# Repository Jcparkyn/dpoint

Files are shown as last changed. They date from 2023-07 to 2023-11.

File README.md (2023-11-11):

# D-POINT: Digital Pen with Optical-Inertial Tracking

**D-POINT** is an open-source digital stylus that uses camera tracking and inertial measurements to achieve 6DoF (six degrees of freedom) inputs, with low latency, pressure sensitivity, and sub-millimetre accuracy.
The stylus can be used on any flat surface, and works with consumer-grade webcams.

<video src="https://github.com/Jcparkyn/dpoint/assets/51850908/21d00ce3-6456-4fba-8c24-4bc8e6642a0d" width="1920" height="1080" autoplay loop muted></video>

This project was part of my undergraduate thesis for electrical engineering. I've open-sourced the code and design files in the hopes that they might be useful to somebody, but it's not intended to be a "plug and play" DIY project. If you want to try building it anyway, follow the [setup guide](./setup-guide.md).

## Design

This is a very brief overview of how the system works. For all the details, plus literature review and lots of evaluation, read the full thesis (note: I haven't published this online yet).

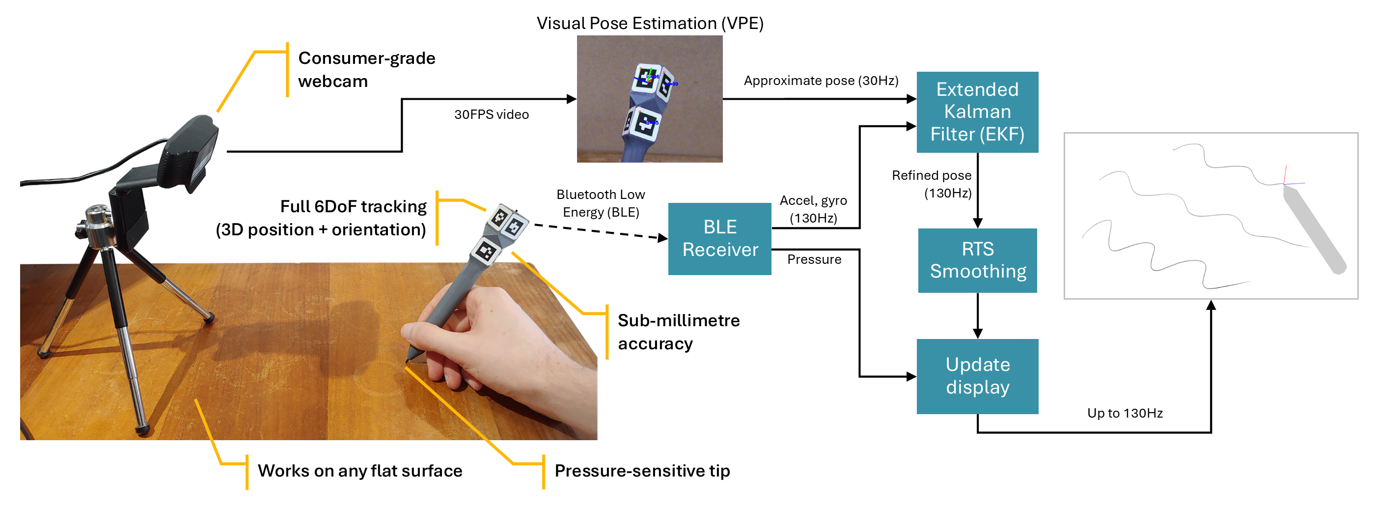
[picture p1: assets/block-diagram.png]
Block diagram showing how the system works


### Hardware

The main body of the stylus was 3D printed as two halves, shown below. The stylus contains a force sensor, a Li-ion battery which charges over USB-C, and an Arduino-based development board for logic and Bluetooth. Eight printed [ArUco](https://www.uco.es/investiga/grupos/ava/portfolio/aruco/) markers are glued to the back of the stylus, for visual pose estimation.

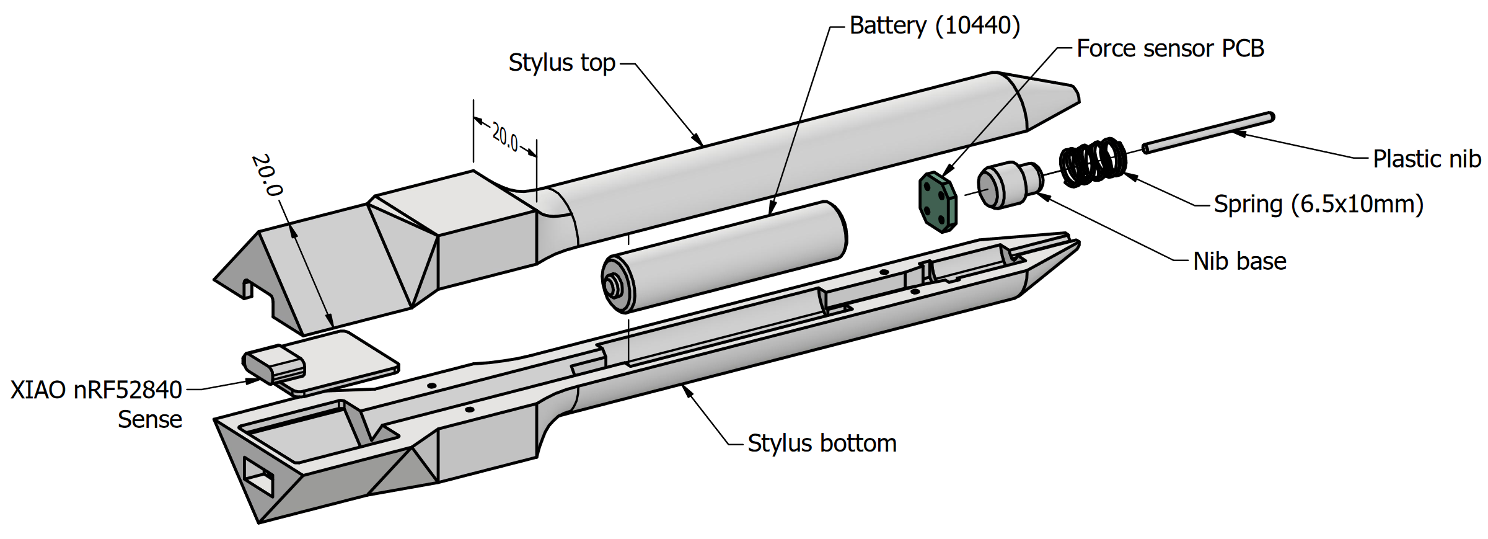
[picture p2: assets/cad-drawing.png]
CAD drawing showing the hardware design of the stylus


### Visual pose estimation (VPE)

The VPE process involves the four main steps:
1. **Marker detection:** First, we use OpenCV to detect the corners of each visible ArUco marker on the stylus.
1. **Rolling shutter correction:** We use a simple 2D motion model to estimate and correct for the effects of [rolling shutter](https://en.wikipedia.org/wiki/Rolling_shutter) on the observed corner locations.
1. **Perspective-n-Point (PnP):** From these corner positions, we use a [PnP](https://en.wikipedia.org/wiki/Perspective-n-Point) algorithm to estimate the pose of the stylus relative to the camera. When possible, we use the pose from the previous frame as a starting point to refine with virtual visual servoing (VVS), otherwise we fall back to SQPnP.
1. **Coordinate conversion:** Using the calibrated pose of the stylus and the drawing surface relative to the camera, we calculate the position and orientation of the stylus tip relative to the drawing surface.

### Inertial fusion

We use an Extended Kalman Filter (EKF) to fuse the VPE estimates with the inertial data from the accelerometer and gyroscope, and refine the estimates in real-time using the Rauch-Tung-Striebel (RTS) algorithm. To account for time delay from the camera frames, we use a negative-time measurement update algorithm. The EKF is implemented using NumPy and [Numba](https://numba.pydata.org/).

Using inertial measurements allows us to dramatically reduce latency compared to a camera-only implementation, while also improving accuracy and report rate for fast movements.

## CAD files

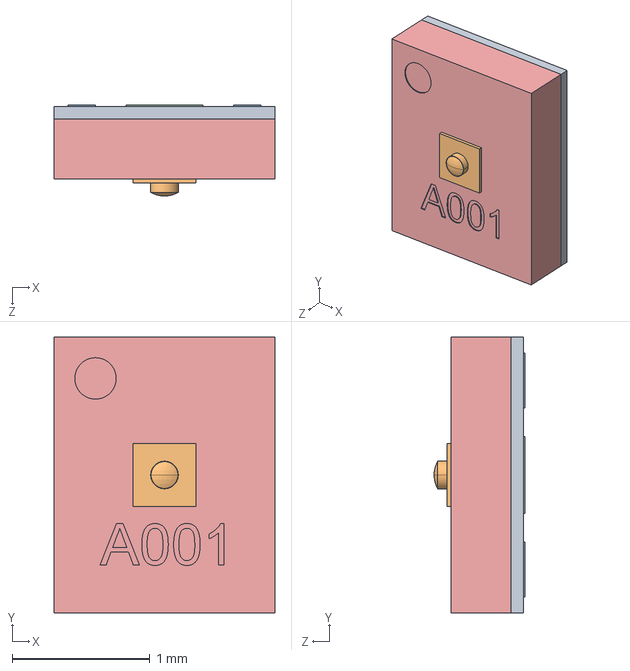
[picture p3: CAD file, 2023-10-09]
electronics/ForceSensor(HSFPAR003A).STEP
1.60 x 2.00 x 0.66 mm

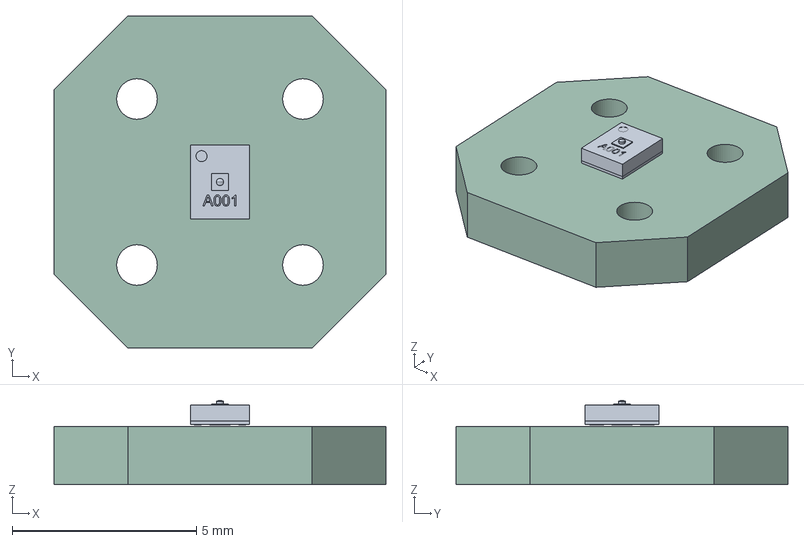
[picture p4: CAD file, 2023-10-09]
print/dpoint.step
9.00 x 9.00 x 2.28 mm
dpoint PCB

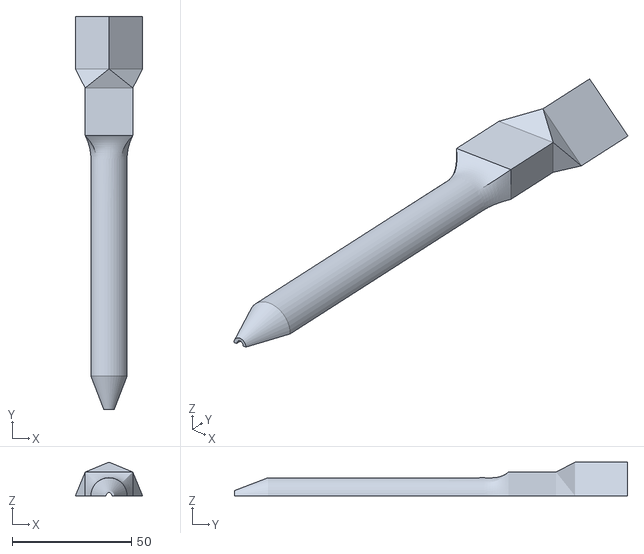
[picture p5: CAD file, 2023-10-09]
print/export/stylus_body_top.stl
28.3 x 165.0 x 14.1

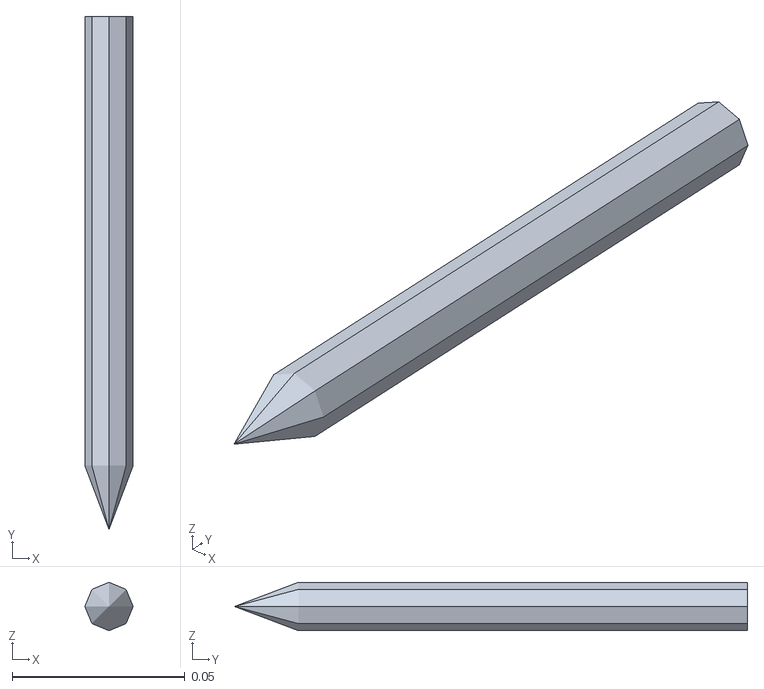
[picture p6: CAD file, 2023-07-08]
python/mesh/pen.obj
0.014 x 0.148 x 0.014

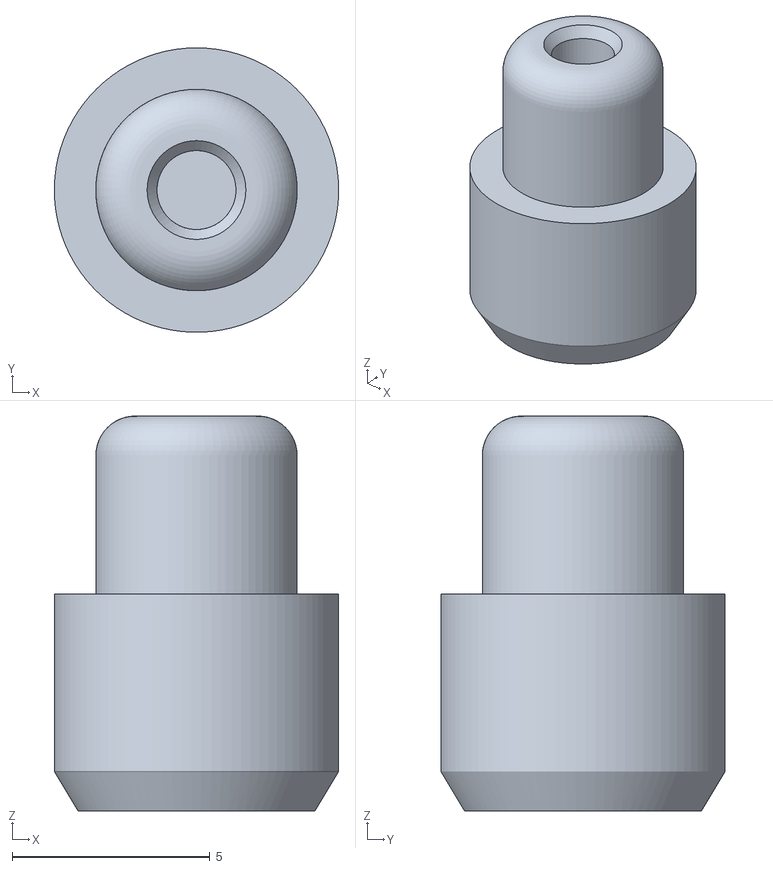
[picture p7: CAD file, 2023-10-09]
print/export/stylus_nib_base.stl
7.20 x 7.20 x 10.0

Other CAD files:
print/drawing.dwg
print/export/stylus_body_bottom.stl
print/Compress Spring11.ipt
print/assembly.iam
print/assembly.ipn
print/batt_10440.ipt
print/seed_arduino.ipt
print/stylus_body.ipt
print/stylus_nib.ipt
print/stylus_nib_base.ipt
python/mesh/pen.blend

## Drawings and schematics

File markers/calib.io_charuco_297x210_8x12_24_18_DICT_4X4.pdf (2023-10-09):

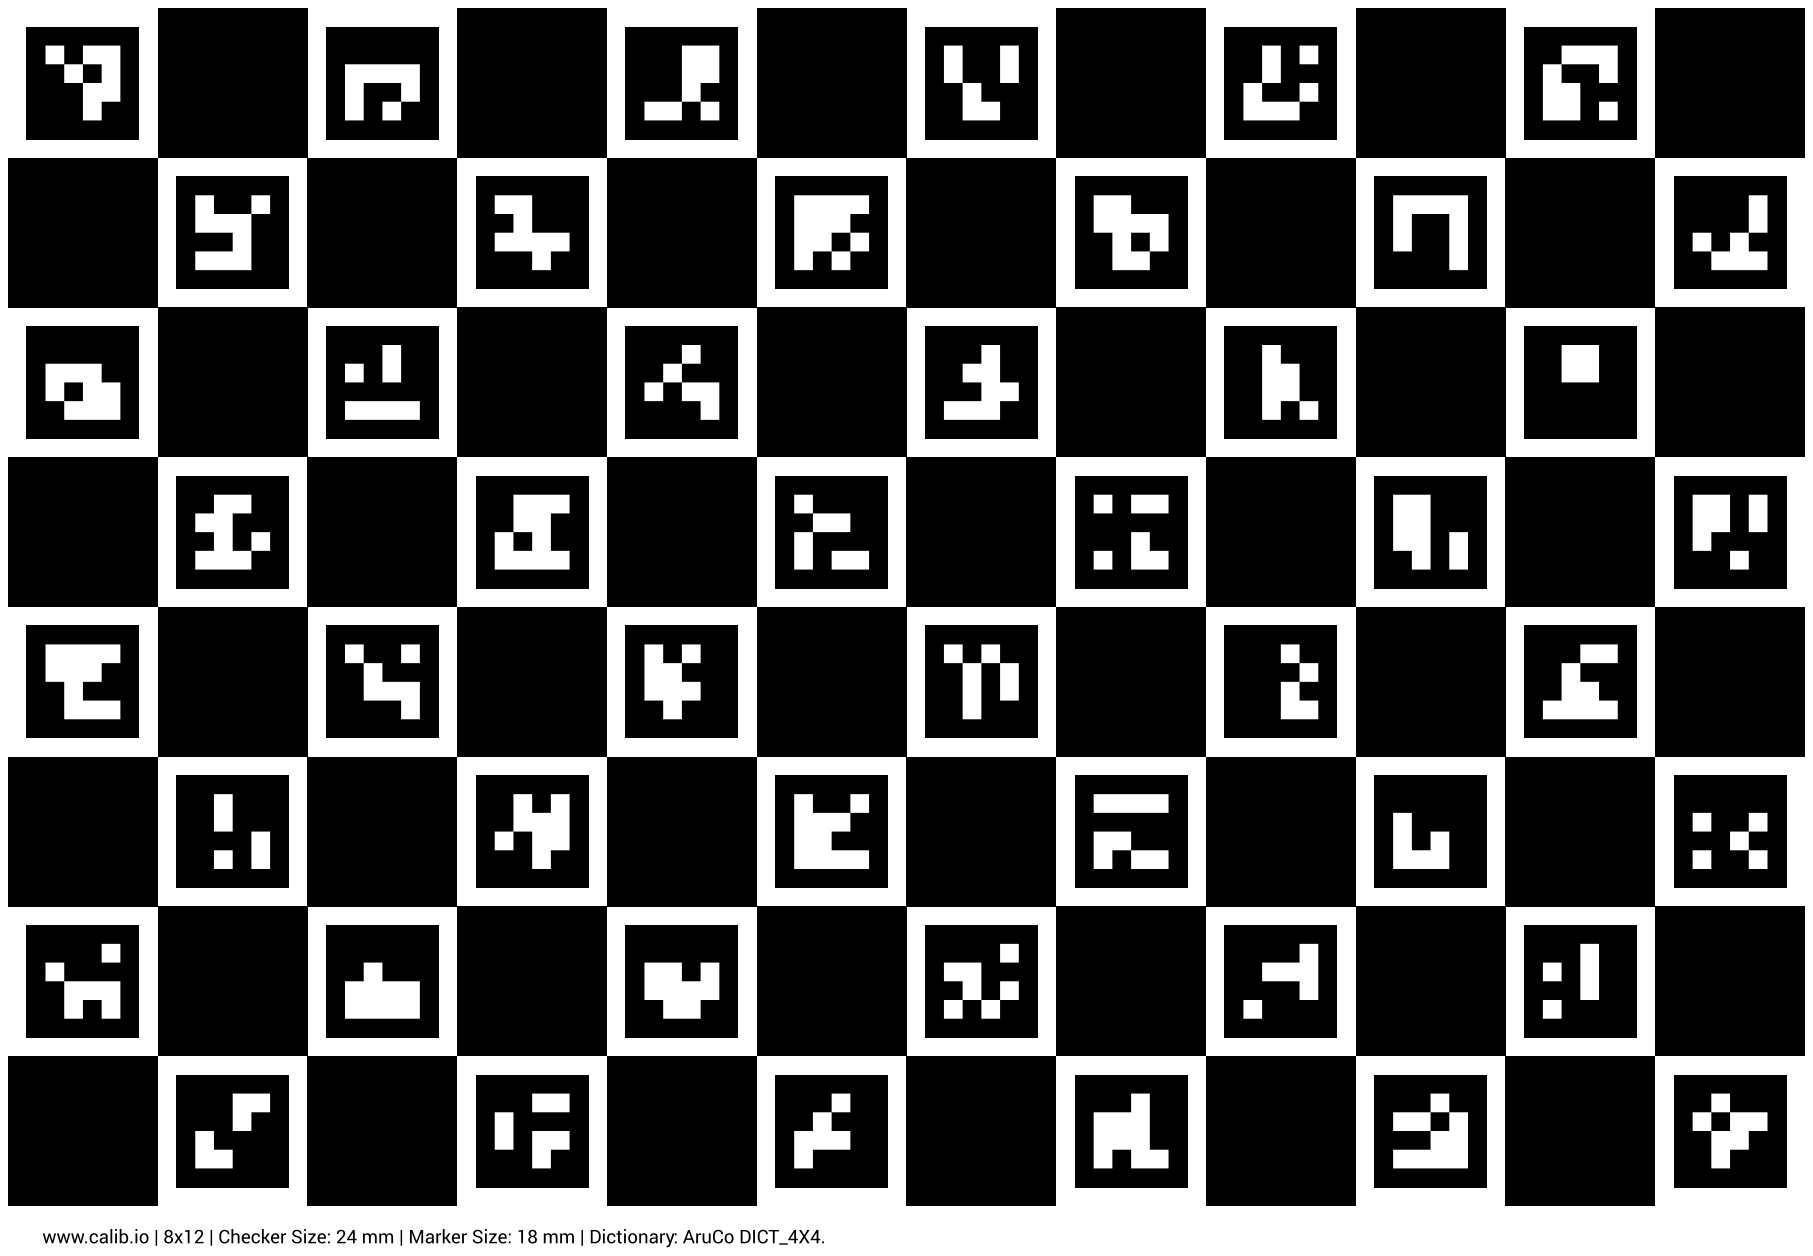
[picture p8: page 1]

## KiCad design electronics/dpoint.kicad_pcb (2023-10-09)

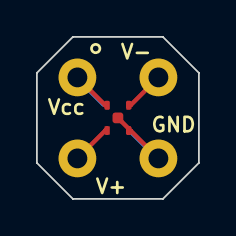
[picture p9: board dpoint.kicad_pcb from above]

Board: 2 copper layers, 9.0 x 9.0 mm, 6 parts (1 on the bottom side), 4 nets.

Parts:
C1: 0.1u; C_0805_2012Metric_Pad1.18x1.45mm_HandSolder
J1, J2, J3, J4: Conn_01x01_Socket; SolderWire-0.5sqmm_1x01_D0.9mm_OD2.1mm
U1: HSFPAR003A; Alps_HSFPAR003A

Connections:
unnamed: C1.1, J4.1, U1.1 (Vdd)
unnamed: J1.1, U1.4 (V1)
unnamed: J2.1, U1.2 (V2)
unnamed: C1.2, J3.1, U1.3 (GND)

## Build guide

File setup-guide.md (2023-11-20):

# Setup guide

As mentioned in the [readme](./README.md), the project is intended as a proof-of-concept (not a "plug-and-play" DIY project), so I can't guarantee that all steps will be easy or perfectly documented. If that's not enough to discourage you, follow the steps below to build and run D-POINT on your own hardware.

Before continuing, [clone](https://docs.github.com/en/repositories/creating-and-managing-repositories/cloning-a-repository) this repository using git:

```bash
git clone https://github.com/jcparkyn/dpoint.git
```

## Building the stylus

<details>
<summary><strong>Tools required</strong></summary>

- A 3D printer, for printing the stylus body. I used a Creality Ender 3, but most types of 3D printer should work.
- Hot air rework station, for soldering the force sensor. You might be able to make do with a soldering iron, but I wouldn't recommend it.
- A soldering iron, for soldering the other electronics.
- An inkjet or laser printer, for printing the ArUco markers.

</details>

<details>
<summary><strong>Parts required</strong></summary>

- Development board: [Seeed Studio XIAO nRF52840 Sense](https://www.seeedstudio.com/Seeed-XIAO-BLE-Sense-nRF52840-p-5253.html).
- Force sensor: Alps Alpine [HSFPAR003A](https://tech.alpsalpine.com/e/products/detail/HSFPAR003A/) or [HSFPAR004A](https://tech.alpsalpine.com/e/products/detail/HSFPAR004A/) (preferred). These can be a little hard to find, but unfortunately, there aren't many other off-the-shelf options aside from FSRs. The [HSFPAR007A](https://tech.alpsalpine.com/e/products/detail/HSFPAR007A/) will also work, but you'll have to modify the PCB footprint.
- Custom PCB: Order this from your PCB manufacturer of choice, using the provided [gerber files](./electronics/gerbers/). Use a PCB thickness of 1.6mm.
- Printer filament. I used PLA, but most hard plastics should work.
- A 6.5x10mm compression spring. I used one from a spring kit (like [this one](https://www.ebay.com.au/itm/175482659706)), but he spring tension does not need to match exactly.
- A 10440 lithium-ion battery (e.g., [this one](https://www.ebay.com/itm/194025159718)).
- Wire, 22-24 AWG for soldering.
- Something to use as a nib for the stylus. I used a [Wacom replacement nib](https://estore.wacom.com/en-au/wacom-standard-replacement-nibs-previous-gen.html), but you might be able to substitute this with something else (e.g., 3D printer filament). If you do, make sure to adjust the dimensions on the 3D model to match.

</details>

### Micro-controller code

To upload the code to the development board:
1. Follow [these instructions](https://wiki.seeedstudio.com/XIAO_BLE/#getting-started) to download the necessary software.
1. Open [microcontroller/dpoint-arduino](./microcontroller/dpoint-arduino/) in the Arduino IDE.
1. Connect the board to your computer using a USB-C cable.
1. Click **Tools > Board > Seeed nRF52 Boards > Seeed XIAO nRF52840 Sense**.
1. Upload the code.

### Build steps

1. Print all three STL files from [print/export/](./print/export/) on your 3D printer.
1. Solder the force sensor to the custom PCB. Make sure to align the top-left of the force sensor (marked with a very small circle) with the circle on the PCB.
1. Solder the force sensor PCB, battery, and development board together using wires, following the schematic below. Make sure to cut wires the right length to fit the stylus body.
1. Place the force sensor PCB, battery, and microcontroller into the bottom half of the 3D printed stylus. The stylus body also has a hole for a switch to disconnect the battery during development, but you can ignore this.
1. Find a small, flat piece of metal or hard plastic, and glue it to the back of the 3D printed nib base where it contacts the force sensor.
1. Insert the nib into the 3D printed nib base, then fit it into the front of the stylus using the spring. You may need to hold it in place until the stylus is fully assembled.
1. Add the top half of the stylus, and secure it in place using tape or glue.
1. Print out the ArUco markers from [markers/stylus-markers.pdf](./markers/stylus-markers.pdf) at 100% scale. This has two copies of each marker (and some spares), but you only need one.
1. Cut carefully along each of the lines around the markers. The white borders are important, so don't cut them off.
1. Glue the markers to the stylus using a glue stick (or your glue of choice). Place them according to the diagram below.
1. Finally, you'll also need a ChArUco board for camera calibration, which you can print using the pattern from [markers/](./markers/). You can either attach this to a flat board, or leave it on your desk.

Wiring diagram:



Marker placement:



## Software setup

The python code requires Python 3.11. I've tried to make sure the codebase works cross-platform, but it's currently only been tested on Windows 10.
You'll also need a relatively powerful CPU to run the application with its current settings. I used an i5-13600KF, but you should be able to get away with something a couple of generations older. If you have performance problems, try changing the settings in [configuration and tuning](#configuration-and-tuning).

1. Open the [python/](./python/) directory (`cd python`).
1. Create and activate a Python [virtual environment](https://docs.python.org/3/tutorial/venv.html#creating-virtual-environments) (optional, but recommended).
1. Install dependencies:
```bash
python -m pip install -r requirements.txt
```
1. Run the camera calibration script (see steps [below](#camera-calibration)). If you're using a Logitech C922 webcam like mine, you may be able to skip this step at the cost of some accuracy.
1. Optional, for better accuracy: Run the [marker calibration script](./python/calibrate_markers.py). Take at least 15 photos of the stylus from different angles (using your calibrated webcam), put them in the `IMAGE_PATH` directory for the script, then run the script.

## Running the application

Run [main.py](./python/main.py). If you have the `python` directory open in VSCode, you can do this by pressing <kbd>F5</kbd>, or running:
```bash
python -m main
```

Put the ChArUco board on your desk in view of the webcam, then press <kbd>C</kbd> (with the camera window focused) to calibrate the camera position.

Make sure the stylus is on - there should be a blue light (if not connected) or green light (if connected) near the USB port. If the stylus is asleep, shake it twice vertically to wake it up.

## Camera calibration
To calibrate your camera:
1. Take 5-10 photos of the ChArUco board from different angles using your webcam.
2. Put the images into `calibration_pics/f30/`.
3. Run `calibrate_camera.py`.

This calibrates the camera intrinsic parameters, but not the camera position or rotation. These are calibrated at run-time.

## Configuration and tuning
Most of the codebase is set up for my own hardware and requirements, so it might not work perfectly for other setups. Here are a list of things to check:

- **Camera exposure:** Auto-exposure is disabled, so you might need to adjust the exposure level in `marker_tracker.py`. Make it as low as you can without the markers failing to detect. Adding a light source will help.
- **Camera time delay:** The code tries to account for the time delay between the camera and IMU readings, which may be different on different systems. Adjust the value of `camera_delay` in `app.py` until you find the value that gives the best accuracy.
- **Camera focus:** The code tries to maintain focus on the stylus markers, but this relies on pre-measured focus values for my camera. If the focus looks wrong for your camera, try adjusting the values in `focus_targets` (`marker_tracker.py`).
- **RTS smoothing:** The filter uses RTS smoothing, which slightly improves accuracy but can be computationally intensive. If you have performance issues, set `smoothing_length` in `app.py` to a smaller value (or zero).
- **Marker search area:** The marker tracker tries to reduce the area of the frame where it looks for markers (this is the green box on the camera preview). If you have performance issues, adjust the value of `expand` in `marker_tracker.py` to reduce the search area for markers in each frame.
- **Camera frame rate:** This isn't directly exposed in the code, and depends on the camera you're using (OpenCV can't reliably set it), but you may want to try running your webcam at 15FPS (or another frame rate) instead of 30FPS. This should give relatively similar accuracy down to about 10-15FPS, and reduce computational requirements, but it might affect the `camera_delay`.
- **IMU update rate:** You can try adjusting the IMU update rate by changing `delayMs` in the [Arduino code](./microcontroller/dpoint-arduino/dpoint-arduino.ino). Make sure to update the corresponing `dt` in `app.py`, and test that the rate you chose is actually being achieved (this is limited by BLE settings and some other things). Ideally, `dt` should be computed automatically from timestamps in the BLE packets, but I removed this at one point and didn't get around to re-implementing it.
- **VSync:** For minimum latency, make sure to disable VSync in your graphics card settings.
- **Camera resolution:** If you try running this at a resolution other than 1920x1080, you'll probably have to tweak some other settings (and re-calibrate your camera).
- **Stylus length:** Depending on the nib you use, the length of your stylus might be slightly different than mine. Adjust `STYLUS_LENGTH` in `dimensions.py` to correct this.
- **Pressure sensor:** With the current wiring, the force sensor gets lots of interference when the USB cable is connected. Make sure to run it wirelessly for full accuracy. The code also tries to account for drift by re-calibrating the sensor whenever it's away from the page, but if you want to draw on 3D objects you'll need to disable this.

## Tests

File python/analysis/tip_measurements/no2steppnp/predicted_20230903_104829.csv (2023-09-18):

0.000988719 | 0.025962645 | 1.5081755e-05
0.0003994761 | 0.024874503 | -0.00031959818
-5.0939714e-05 | 0.02520879 | -0.00093396544
-0.00061105535 | 0.025585424 | -0.0004126248
0.0006081067 | 0.025196314 | -0.0011514479
-5.0023114e-05 | 0.026214939 | -0.000998219
-0.0011631214 | 0.025433293 | -0.0007946275
-0.0015963342 | 0.024322614 | 0.0003280963
-0.0009729329 | 0.024746282 | -0.0004860177
8.127195e-05 | 0.024458982 | -0.0009467948
-2.3815928e-05 | 0.14483851 | -0.00057031884
0.00033275783 | 0.14404711 | -0.00069739425
0.00021030256 | 0.14434724 | -0.0005502042
-0.00033741855 | 0.14444739 | -0.00045044706
-0.00017841718 | 0.14336857 | -0.0003970959
-0.00019879515 | 0.1433702 | -0.00028272715
-7.8505254e-05 | 0.14329271 | -0.00032725665
0.0009281744 | 0.1466855 | -0.0006902015
0.00079110765 | 0.14337167 | -0.00027919322
-0.00011933327 | 0.14356677 | -0.00014511406
0.0003138622 | 0.26272592 | -0.0006527511
0.0008508221 | 0.26250455 | -0.0011773211
-0.00033299095 | 0.26208067 | -0.000637439
0.001032939 | 0.26248762 | -0.00091222115
0.0006040647 | 0.26181027 | -0.0008861628
-0.00066502753 | 0.2594022 | -0.0012327172
0.0010597635 | 0.26068798 | -0.0006799782
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

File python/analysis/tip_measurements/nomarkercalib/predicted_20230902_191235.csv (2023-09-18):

0.0014141263 | 0.024553621 | 5.8834168e-05
0.0023236386 | 0.02523166 | -8.966219e-05
0.0015790227 | 0.026338127 | -0.0005602371
0.00024782165 | 0.025628017 | -0.00014026067
0.00094174786 | 0.025512496 | 6.263566e-05
0.0004122328 | 0.14360198 | 6.1106846e-05
0.00093417586 | 0.14414872 | -0.0002516737
0.0010865261 | 0.14363435 | -0.00031100702
0.0006521406 | 0.14537634 | -2.2045893e-05
0.0015282324 | 0.14462824 | -0.0006252238
-0.00018699863 | 0.1444019 | 0.00024900382
-0.0006599318 | 0.14404143 | 0.0004414377
0.0007905522 | 0.14370933 | -0.00021530614
0.0014647718 | 0.14423636 | -0.00011577799
0.0014899628 | 0.14449194 | -7.174196e-05
0.0009383219 | 0.024725506 | 0.00010030966
0.0013567837 | 0.02567877 | 0.00013983343
-6.125108e-06 | 0.024196347 | -0.00048550405
0.0016938101 | 0.025339687 | -6.674391e-05
-0.0007620022 | 0.026337849 | 0.0004691193
0.00052437466 | 0.2635748 | 2.0806963e-05
0.00069621496 | 0.2642158 | 0.0001255706
0.0007566231 | 0.26430744 | -0.00048155617
0.00046326534 | 0.26376262 | -0.00016481453
-0.00022522412 | 0.26451325 | 0.00019521681
-0.001210059 | 0.26380408 | 0.00024083661
-0.00036001968 | 0.2630329 | -5.96105e-06
0.0010297245 | 0.2633452 | -0.00033040126
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

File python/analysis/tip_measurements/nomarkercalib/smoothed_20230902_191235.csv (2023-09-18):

0.0016742414 | 0.024450984 | 5.7748148e-05
0.0018236212 | 0.02506619 | -2.1763663e-05
0.0013008809 | 0.025562134 | -0.0003653401
0.00043026748 | 0.025447594 | -0.00015804893
0.0011996034 | 0.024831023 | -0.00016407818
0.00019753393 | 0.14342597 | -0.00015245653
0.0010958357 | 0.14434528 | -0.00013294857
0.0015905233 | 0.14361745 | -0.00016152325
0.0010257148 | 0.14490484 | -9.178967e-05
0.0014786121 | 0.14416517 | -0.0003871435
-2.3638711e-05 | 0.14406408 | 0.00023682184
-0.00079716014 | 0.14315985 | 0.00028282715
0.0006409988 | 0.14352158 | -0.0002710929
0.0014790358 | 0.14449689 | -0.00020674539
0.0020802314 | 0.14439535 | -3.66339e-05
0.00094449334 | 0.024958648 | -6.465695e-05
0.0018162183 | 0.02506369 | -4.1450796e-05
0.00023790926 | 0.025245018 | -0.0002989177
0.001561813 | 0.024836395 | -0.00011486184
-0.0005173678 | 0.025556246 | 0.0002932321
0.0009506509 | 0.26418257 | -0.000264499
0.00097116426 | 0.26452184 | 3.196023e-05
0.00017269785 | 0.26383412 | -0.0005285385
0.00014483406 | 0.2641118 | -0.00022902
0.0005305559 | 0.26477817 | 0.00014491081
-0.00069827586 | 0.262862 | 0.00018413611
-0.00038334014 | 0.2625968 | -6.1392406e-05
0.00055882183 | 0.2635401 | -0.00037180036
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

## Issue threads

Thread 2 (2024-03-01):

UKF Implementation

TsingLoo, 2024-03-01:
I want to propose the consideration of implementing the Unscented Kalman Filter (UKF) instead of the current Extended Kalman Filter (EKF) for sensor fusion in the project.

I wonder, if it's possible to encapsulate the actual filter implementation by using abstract or interface-like calls in the update_imu and update_camera functions.

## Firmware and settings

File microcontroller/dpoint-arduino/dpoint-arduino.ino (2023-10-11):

#include <Adafruit_SPIFlash.h>
#include <LSM6DS3.h>
#include <Wire.h>
#include <bluefruit.h>
#include <nrf52840.h>
#include <nrf_saadc.h>
#include <nrf_power.h>

#define LEDR LED_RED
#define LEDG LED_GREEN
#define LEDB LED_BLUE

#define PRESSURE_SENSOR_VCC_PIN D1
#define PRESSURE_SENSOR_SAADC_CHANNEL 0

const unsigned long delayMs = 7;
const unsigned long rate = 1000/delayMs;
const unsigned long stayAwakeTimeMs = 1000*60;

struct IMUDataPacket {
  int16_t accel[3];
  int16_t gyro[3];
  uint16_t pressure;
};

const uint8_t LBS_UUID_SERVICE[] =
{
  0x19, 0xB1, 0x00, 0x10, 0xE8, 0xF2, 0x53, 0x7E, 0x4F, 0x6C, 0xD1, 0x04, 0x76, 0x8A, 0x12, 0x14
};

// 19B10013-E8F2-537E-4F6C-D104768A1214
const uint8_t LBS_UUID_CHR_IMU[] =
{
  0x14, 0x12, 0x8A, 0x76, 0x04, 0xD1, 0x6C, 0x4F, 0x7E, 0x53, 0xF2, 0xE8, 0x13, 0x00, 0xB1, 0x19
};

BLEService bleService(LBS_UUID_SERVICE);
BLECharacteristic imuCharacteristic(LBS_UUID_CHR_IMU);

Adafruit_FlashTransport_QSPI flashTransport;
LSM6DS3 imu(I2C_MODE, 0x6A); //I2C device address 0x6A

const nrf_saadc_channel_config_t adcConfig = {
  .resistor_p = NRF_SAADC_RESISTOR_DISABLED,
  .resistor_n = NRF_SAADC_RESISTOR_DISABLED,
  .gain       = NRF_SAADC_GAIN4,
  .reference  = NRF_SAADC_REFERENCE_VDD4,
  .acq_time   = NRF_SAADC_ACQTIME_20US,
  .mode       = NRF_SAADC_MODE_DIFFERENTIAL,
  .burst      = NRF_SAADC_BURST_ENABLED,
};

// Disable QSPI flash to save power
void QSPIF_sleep(void)
{
  flashTransport.begin();
  flashTransport.runCommand(0xB9);
  flashTransport.end();
}

void imuISR() {
  // Interrupt triggers for both single and double taps, so we need to check which one it was.
  uint8_t tapSrc;
  status_t status = imu.readRegister(&tapSrc, LSM6DS3_ACC_GYRO_TAP_SRC);
  bool wasDoubleTap = (tapSrc & LSM6DS3_ACC_GYRO_DOUBLE_TAP_EV_STATUS_DETECTED) > 0;
  if (!wasDoubleTap) {
    nrf_power_system_off(NRF_POWER);
  }
}

void setupWakeUpInterrupt()
{
  // Tap interrupt code is based on code by daCoder
  // https://forum.seeedstudio.com/t/xiao-sense-accelerometer-examples-and-low-power/270801
  imu.settings.gyroEnabled = 0;
  imu.settings.accelEnabled = 1;
  imu.settings.accelSampleRate = 104;
  imu.settings.accelRange = 2;
  imu.begin();

  //https://www.st.com/resource/en/datasheet/lsm6ds3tr-c.pdf
  imu.writeRegister(LSM6DS3_ACC_GYRO_TAP_CFG1, 0b10001000); // Enable interrupts and tap detection on X-axis
  imu.writeRegister(LSM6DS3_ACC_GYRO_TAP_THS_6D, 0b10001000); // Set tap threshold
  const int duration = 0b0010 << 4; // 1LSB corresponds to 32*ODR_XL time
  const int quietTime = 0b10 << 2; // 1LSB corresponds to 4*ODR_XL time
  const int shockTime = 0b01 << 0; // 1LSB corresponds to 8*ODR_XL time
  imu.writeRegister(LSM6DS3_ACC_GYRO_INT_DUR2, duration | quietTime | shockTime); // Set Duration, Quiet and Shock time windows
  imu.writeRegister(LSM6DS3_ACC_GYRO_WAKE_UP_THS, 0x80); // Single & double-tap enabled (SINGLE_DOUBLE_TAP = 1)
  imu.writeRegister(LSM6DS3_ACC_GYRO_MD1_CFG, 0x08); // Double-tap interrupt driven to INT1 pin
  imu.writeRegister(LSM6DS3_ACC_GYRO_CTRL6_G, 0x10); // High-performance operating mode disabled for accelerometer

  // Set up the sense mechanism to generate the DETECT signal to wake from system_off
  pinMode(PIN_LSM6DS3TR_C_INT1, INPUT_PULLDOWN_SENSE);
  attachInterrupt(digitalPinToInterrupt(PIN_LSM6DS3TR_C_INT1), imuISR, CHANGE);

  return;
}

void setupPressureSensor() {
  pinMode(PRESSURE_SENSOR_VCC_PIN, OUTPUT);
  digitalWrite(PRESSURE_SENSOR_VCC_PIN, HIGH);

  nrf_saadc_enable(NRF_SAADC);

  nrf_saadc_oversample_set(NRF_SAADC, NRF_SAADC_OVERSAMPLE_32X);
  nrf_saadc_resolution_set(NRF_SAADC, NRF_SAADC_RESOLUTION_12BIT);
  nrf_saadc_channel_input_set(NRF_SAADC, PRESSURE_SENSOR_SAADC_CHANNEL, NRF_SAADC_INPUT_AIN2, NRF_SAADC_INPUT_AIN4);
  nrf_saadc_channel_init(NRF_SAADC, PRESSURE_SENSOR_SAADC_CHANNEL, &adcConfig);

  NRF_SAADC->TASKS_CALIBRATEOFFSET = 1;
  while (NRF_SAADC->EVENTS_CALIBRATEDONE == 0);
  NRF_SAADC->EVENTS_CALIBRATEDONE = 0;
  while (NRF_SAADC->STATUS == (SAADC_STATUS_STATUS_Busy << SAADC_STATUS_STATUS_Pos));

  nrf_saadc_disable(NRF_SAADC);
}

int16_t readPressure() {
  volatile nrf_saadc_value_t result = -1;

  nrf_saadc_enable(NRF_SAADC);
  nrf_saadc_continuous_mode_disable(NRF_SAADC);

  NRF_SAADC->RESULT.MAXCNT = 1;
  NRF_SAADC->RESULT.PTR = (uint32_t)&result;

  // Start the SAADC and wait for the started event.
  NRF_SAADC->TASKS_START = 1;
  while (NRF_SAADC->EVENTS_STARTED == 0);
  NRF_SAADC->EVENTS_STARTED = 0;

  // Do a SAADC sample, will put the result in the configured RAM buffer.
  NRF_SAADC->TASKS_SAMPLE = 1;
  while (NRF_SAADC->EVENTS_END == 0);
  NRF_SAADC->EVENTS_END = 0;

  NRF_SAADC->TASKS_STOP = 1;
  while (NRF_SAADC->EVENTS_STOPPED == 0);
  NRF_SAADC->EVENTS_STOPPED = 0;

  nrf_saadc_disable(NRF_SAADC);

  // Scaling to match previous mbed implementation
  return int16_t((uint32_t(result) * 0xFFFF) / 0x0FFF);
}

void setupImu() {
  imu.settings.accelRange = 4; // Can be: 2, 4, 8, 16
  imu.settings.gyroRange = 500; // Can be: 125, 245, 500, 1000, 2000
  imu.settings.accelSampleRate = 416; //Hz.  Can be: 13, 26, 52, 104, 208, 416, 833, 1666, 3332, 6664, 13330
  imu.settings.gyroSampleRate = 416; //Hz.  Can be: 13, 26, 52, 104, 208, 416, 833, 1666
  imu.settings.accelBandWidth = 200;
  imu.settings.gyroBandWidth = 200;
  imu.begin();
}

void runBle() {
  while (Bluefruit.connected(0)) {
    unsigned long startTime = millis();

    IMUDataPacket packet;
    // This could be optimised by reading all values as a block.
    packet.accel[0] = imu.readRawAccelX();
    packet.accel[1] = imu.readRawAccelY();
    packet.accel[2] = imu.readRawAccelZ();
    packet.gyro[0] = imu.readRawGyroX();
    packet.gyro[1] = imu.readRawGyroY();
    packet.gyro[2] = imu.readRawGyroZ();

    packet.pressure = readPressure();
    
    imuCharacteristic.notify(&packet, sizeof(packet));

    // Inaccurate but usable way to throttle the rate of measurements.
    unsigned long time = millis() - startTime;
    unsigned long waitPeriod = delayMs - time;
    if (waitPeriod > 0 && waitPeriod < 500) { // protection against overflow issues
      delay(waitPeriod);
    }
  }
}

void startAdvertising()
{
  Bluefruit.Advertising.addFlags(BLE_GAP_ADV_FLAGS_LE_ONLY_GENERAL_DISC_MODE);
  Bluefruit.Advertising.addTxPower();
  Bluefruit.Advertising.addService(bleService);

  Bluefruit.ScanResponse.addName();
  
  Bluefruit.Advertising.restartOnDisconnect(true);
  Bluefruit.Advertising.setInterval(128, 488);    // in unit of 0.625 ms
  Bluefruit.Advertising.setFastTimeout(30);      // number of seconds in fast mode
  Bluefruit.Advertising.start(0);                // 0 = Don't stop advertising after n seconds
}

void sleepUntilDoubleTap() {
  digitalWrite(LEDR, HIGH);
  digitalWrite(LEDG, HIGH);
  digitalWrite(LEDB, HIGH);

  Serial.println("Setting up interrupt");
  // Setup up double tap interrupt to wake back up
  setupWakeUpInterrupt();

  Serial.println("Entering sleep");
  Serial.flush();

  // Execution should not go beyond this
  nrf_power_system_off(NRF_POWER);
}

void setup() {
  Serial.begin(9600);
  // while (!Serial && millis() < 1000); // Timeout in case serial disconnected.
  pinMode(LEDR, OUTPUT);
  pinMode(LEDG, OUTPUT);
  pinMode(LEDB, OUTPUT);
  digitalWrite(LEDR, LOW);
  digitalWrite(LEDG, HIGH);
  digitalWrite(LEDB, HIGH);

  QSPIF_sleep();

  Bluefruit.autoConnLed(false);
  Serial.println("Initialise the Bluefruit nRF52 module");
  Bluefruit.configPrphBandwidth(4); // max is BANDWIDTH_MAX = 4
  Serial.print("Begin Bluefruit: ");
  Serial.println(Bluefruit.begin(1, 0));
  Bluefruit.Periph.setConnInterval(6, 6);
  Bluefruit.setName("DPOINT");
  Serial.println("Begin bleService");
  bleService.begin();

  imuCharacteristic.setProperties(CHR_PROPS_READ | CHR_PROPS_NOTIFY);
  imuCharacteristic.setPermission(SECMODE_OPEN, SECMODE_NO_ACCESS);
  imuCharacteristic.setFixedLen(sizeof(IMUDataPacket));
  Serial.println("Begin imuCharacteristic");
  imuCharacteristic.begin();
  IMUDataPacket initialPacket = { 0 };
  imuCharacteristic.write(&initialPacket, sizeof(initialPacket));

  Serial.println("Setup finished");
}

void loop() {
  Serial.print("Starting advertising...");
  startAdvertising();
  digitalWrite(LEDR, HIGH);
  digitalWrite(LEDG, HIGH);
  digitalWrite(LEDB, LOW);

  Serial.print("Starting IMU...");
  setupImu();

  unsigned long wakeUpTime = millis();

  while (millis() - wakeUpTime < stayAwakeTimeMs) {
    if (Bluefruit.connected(0)) {
      Serial.println("Connected");
      setupPressureSensor();
      digitalWrite(LEDR, HIGH);
      digitalWrite(LEDG, LOW);
      digitalWrite(LEDB, HIGH);
      runBle();
      digitalWrite(LEDR, HIGH);
      digitalWrite(LEDG, HIGH);
      digitalWrite(LEDB, LOW);
      digitalWrite(PRESSURE_SENSOR_VCC_PIN, LOW);
      wakeUpTime = millis();
    }
    // Don't sleep if USB connected, to make code upload easier.
    if (Serial) wakeUpTime = millis();
    delay(100);
  }
  Serial.println("Stopping advertising");
  Bluefruit.Advertising.stop();
  sleepUntilDoubleTap();
}

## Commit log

2023-06-19 Update parameter values for 120Hz
2023-06-19 Change default camera position
2023-06-19 Add arduino code to repo
2023-06-27 Increase IMU sample rate and tweak constants
2023-06-28 Add improved camera calibration using a charuco board
2023-06-28 Use charuco board for camera pose estimation
2023-06-28 Replace box visualisation with custom mesh
    [pen.blend]
2023-07-03 Use BLE for transmitting IMU data
2023-07-07 Improve PnP algorithm to switch between refinement and EPnP
2023-07-07 Move default camera to focus on middle of charuco board
2023-07-08 Convert EKF to z-up coordinate system
    [pen.blend, pen.obj]
2023-07-08 Switch to contour corner refinement
2023-07-09 Switch to VVS pose refinement, which appears to diverge less often than LM
2023-07-10 Fix initial calibration handling
2023-07-11 MCU improvements
    - Better BLE handling
    - RGB status LED
    - Sleep when BLE idle
2023-07-11 Update process values for sensor bias
2023-07-12 Implement forward-prediction from IMU data
2023-07-16 Update filter params
2023-07-16 Improve filter reset logic
2023-07-23 Implement firmware and software for pressure sensitivity
2023-07-31 Update pressure values for new nib
2023-07-31 Remove unneeded print
2023-08-02 Use NamedTuple for camera readings
2023-08-15 Add code for computing camera covariance matrix
2023-08-20 Switch to 2D agg line for better rendering quality
2023-08-28 Implement marker calibration and minor refactoring
2023-08-28 Clean up filter code
2023-08-28 Add option to switch to 3D line
2023-09-05 Set bandwidths for IMU
2023-09-06 Refactor handling of smoothing_length in filter
2023-09-06 Implement raw frame recording
2023-09-10 Add cameraonly plot
2023-09-12 Make fps plot use period for x axis
2023-09-17 Reduce BLE connection interval, and read pressure first
2023-09-17 Increase rate to 130Hz
2023-09-17 Adjust filter params
2023-09-17 Reduce camera exposure
2023-09-17 Convert calibratedMarkerPositions to JSON
2023-09-17 Move camera params file
2023-09-17 Move pen OBJ
    [pen.obj]
2023-09-18 Move some things to analysis dir
    [predicted_20230902_143553.csv, predicted_20230902_191235.csv, predicted_20230903_104829.csv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]
2023-09-18 Move latency measurements to analysis dir
    [latencies.csv]
2023-09-19 Don't crash if camera calibration fails
2023-10-01 Set battery charge rate to 100mA
2023-10-06 Add comment for AIN error
    [dpoint-arduino.ino]
2023-10-06 Replace MCU code with non-mbed implementation
    [dpoint-arduino.ino]
2023-10-09 Add KiCad files
    [ForceSensor(HSFPAR003A).STEP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]
2023-10-09 Add 3D print files
    [Compress Spring11.ipt, assembly.iam, assembly.ipn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]
2023-10-10 Skip rendering points where both ends have zero pressure
2023-10-11 Improve tap interrupt parameters
2023-11-08 Switch to DICT_4X4 aruco board
2023-11-11 Update board details for calibrate_camera
2023-11-11 Fix typo in filename
    [assembly.iam, stlyus_body.ipt, stylus_body.ipt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]
2023-11-20 Add more detail to setup guide
    - platform info
    - configuration and tuning
    - missing sentence about LEDs
2023-11-27 Fix charuco board for camera calibration
